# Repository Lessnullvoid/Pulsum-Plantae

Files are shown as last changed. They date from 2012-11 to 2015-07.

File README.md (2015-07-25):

# Pulsum-Plantae
Pulsum Plantae is a project focused on bioelectrical activity readings from different types of plants. Using their perceptual skills as biosensors, amplifying the signals to be sent to a microncontrolador and to work with them in a process of experimental sonification. This repository contains all the parts necessary to make pulsum plantae system run. Check our website for other examples http://lessnullvoid.cc/pulsum send us and email at info@interspecifics.cc 

The Plants, Leslie Garcia, Thiago Hersan, Paloma López and many other collaborators. 

#Hardware
The LM324N is the core of the circuit, consists of four independent, high-gain, internally frequency-compensated operational amplifiers designed specifically to operate from a single power supply over a wide range of voltages. for more information read the datashet: http://pdf.datasheetcatalog.com/datasheet/philips/LM324N.pdf
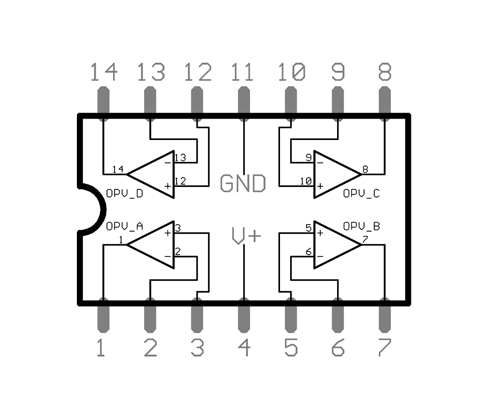
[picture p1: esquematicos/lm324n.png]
Operation Amplifier


**Biosensor circuit for bio-electrical readings**
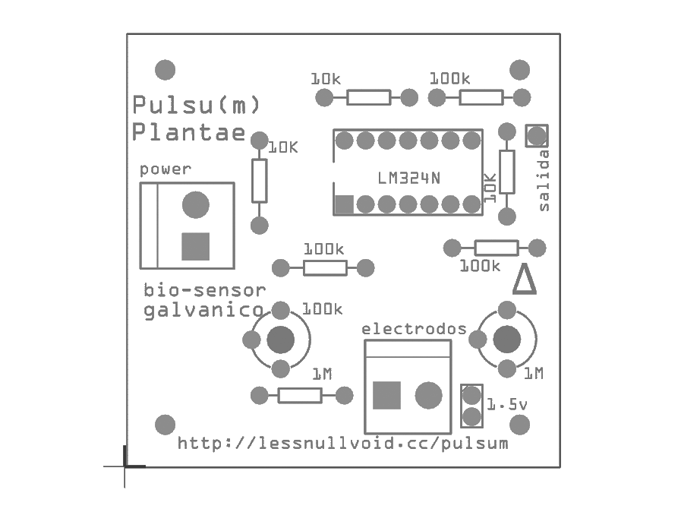
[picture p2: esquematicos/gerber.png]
Gerber file


- [Download Fritzing file here:](https://github.com/Lessnullvoid/Pulsum-Plantae/blob/master/pcb/GalvanicoLM324Final.fzz)
- [Download the pdf etchable file here:](https://github.com/Lessnullvoid/Pulsum-Plantae/tree/master/pcb/pdfLM324Final)
- [Download the gerber file here:](https://github.com/Lessnullvoid/Pulsum-Plantae/tree/master/pcb/GalvanicoLM324_Gerber_Final)
- [We have some circuits available to sell, just send us an email](info@interspecifics.cc)

**List of components for the circuit:**
- 1 LM324N
- 3 100K resistors
- 3 10K resistors
- 1 1M resistor
- 1 100K trimpot
- 1 1M trimpot
- 2 terminals
- 2 gel electrodes
- 2 acupunture needles
- 1 jumper wire

#Installation 

**Prepare your arduino and circuits**

- 1 Download the Pulsum-Plante master to your computer.
- 2 Load the pulsumSensorRead software in your arduino [find the code here.](https://github.com/Lessnullvoid/Pulsum-Plantae/blob/master/arduino/pulsumSensorRead/pulsumSensorRead.ino)
- 3 connect your circuit power terminal to the arduino power 3.3V.
- 4 plug the output pin from the pulsum circuit to your analog input in arduino.
- 5 plug your electrodes to the terminal electrodes pin in your pulsum circuit.
- 6 connect the electrodes to your plant.

#Software

- [Download a zip file with the compile version of PulsumOSC here:](http://lessnullvoid.cc/download/PulsumOscDebug.zip)
- [Compile your own PulsumOSC, fing the code here:](https://github.com/Lessnullvoid/Pulsum-Plantae/tree/master/PulsumOsc)

After preparing the circuit and pluged to the arduino board, you are ready to test the system using the software we provided here. We have a tool called PulsumOSC is a OpenFrameWorks program that runs on Mac 0SX 10.7, 10.8, 10.9, 10.10. To run the software you need to select your serial port on the serial list.

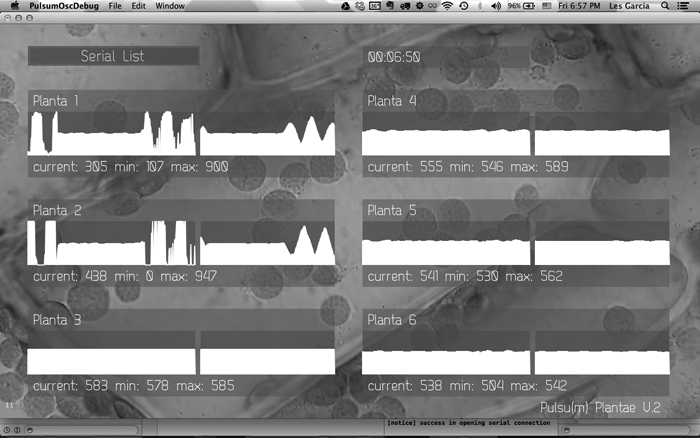
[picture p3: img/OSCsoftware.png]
PulsumOsc


After running, the software starts serving OSC values in the following arrangement: 

 ```
OSC0/filtrado/data OSC0/crudo/data OSC0/min/data OSC0/max/data
OSC1/filtrado/data OSC1/crudo/data OSC1/min/data OSC1/max/data
OSC2/filtrado/data OSC2/crudo/data OSC2/min/data OSC2/max/data
OSC3/filtrado/data OSC3/crudo/data OSC3/min/data OSC3/max/data
OSC4/filtrado/data OSC4/crudo/data OSC4/min/data OSC4/max/data
```
The number after the OSC indicates the analog input where you pluged the sensor.

This values are processed in the sensor.h file as follows:
 ```
const unsigned short getMin() const;
const unsigned short getMax() const;
const unsigned short getRawValue() const;
const unsigned short getAverageValue() const;
const unsigned short getAverageValueNormalized() const;
 ```
 **Note for linux and windows users**
 
There is also a processing version of this software to perform the same transmision of data in OSC you can check the [code here.](https://github.com/Lessnullvoid/Pulsum-Plantae/tree/master/processing/PulsumOsc)

**DSP PureData and other programs**

After running any of this software's your ar good to run the puredata part in the system. This specific patch is a granular synth. Is important to preload a sound sample on every module. By default the outputs are setup in a quadraphonic arrangement, so every module send to ~DAC1 ~DAC2 ~DAC3 and so on. You can control this on the output panel. 
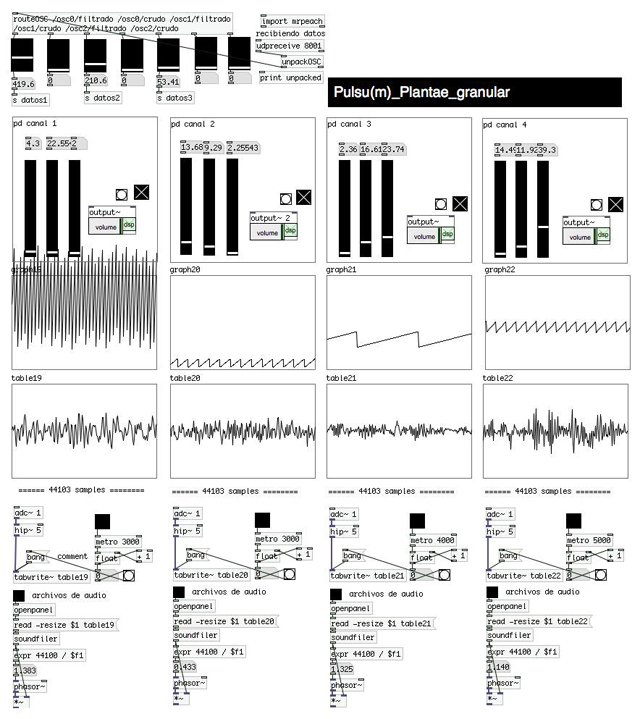
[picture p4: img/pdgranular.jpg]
pd granular
 
 
 **Start the patch**
 - Load a grain of sound 0.1 milisecond on loadpanel for every channel
 - High the volume on the output~ box 
 - Ajust the OSC data receiver on the routeOSC part to match your prefered arrangment 
 - The OSC data es controlling 3 parameters for every granular synth, frequency, amplitud, position.
 - Listen to your plants playing granular synths :)

This is a first version of the software for sonification. Both versions are available. 
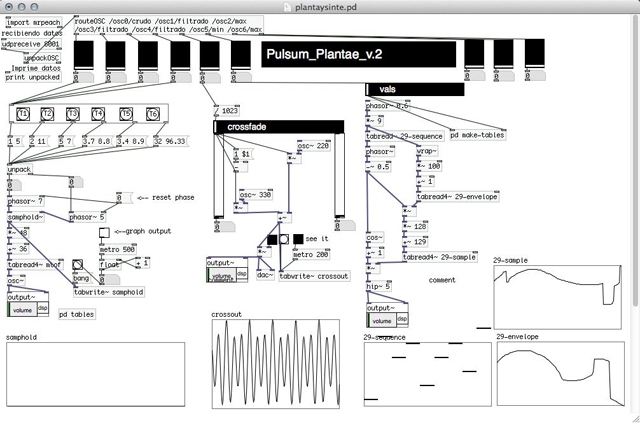
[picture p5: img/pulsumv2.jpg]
pd plantSynth
 

#Some notes on electrodes

Here is three different types of electrodes to plug your plants, this depends on the physiological features of the plant you are attempting to connect. For best results we recommend to test the three options and check the results with the monitor software.

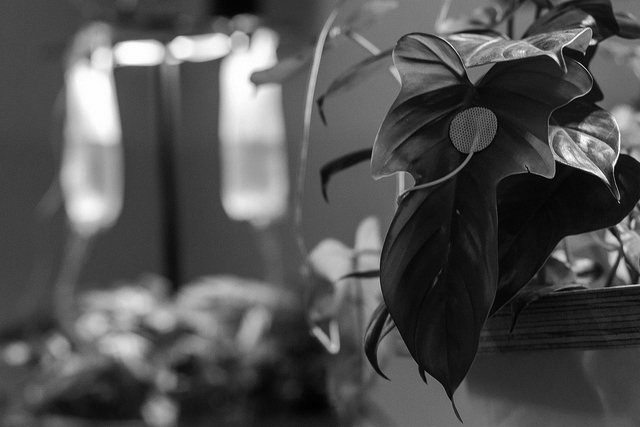
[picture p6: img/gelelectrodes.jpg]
Gel electrodes for long leaves
- The gel electrodes are specially good for long leaves, the best are the circular ones use for facial treatment. They are small and reusable, so you can clean after using, just with a little of wather: 

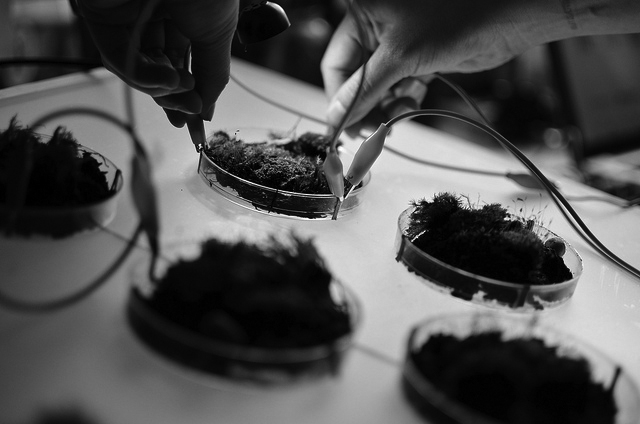
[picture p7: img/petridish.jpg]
Petridish
- The petri dish system uses aluminum tape place in a Y form. This type of electrodes work with mosses or algae or other type of small plants. You can also work with copper tape, but is important to consider the process of corrosion is faster on copper than aluminum. And this could poison your plants. 

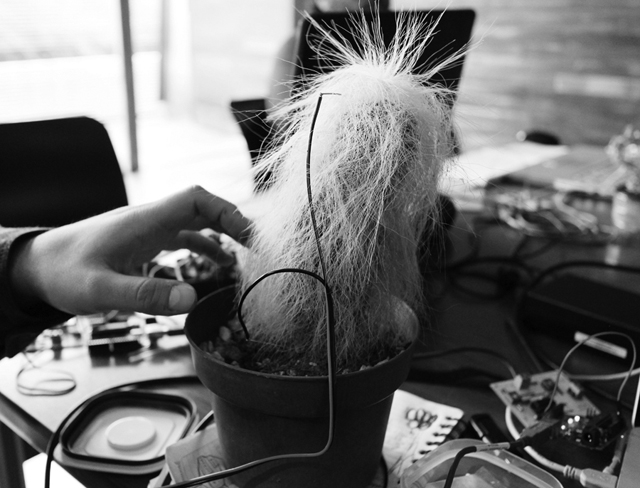
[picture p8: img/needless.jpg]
Needles
- The acupuncture  needles are specially good for cactacea or suculente type of plants, they are made out stainless steel, that means you can leave the needles inside the cactus for long time with no problems.

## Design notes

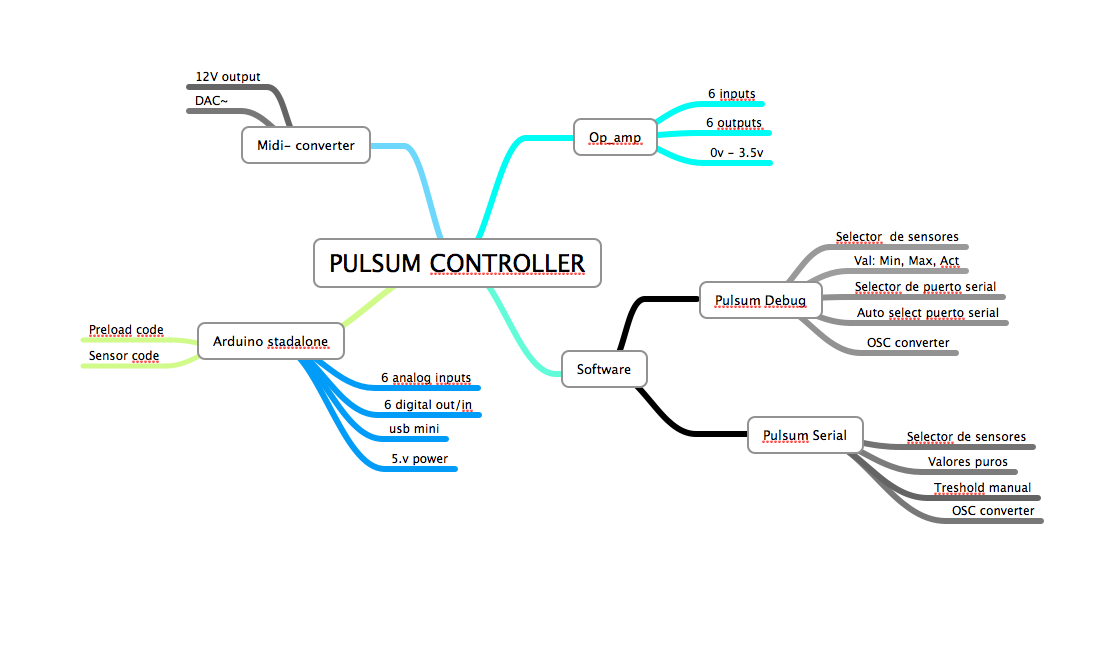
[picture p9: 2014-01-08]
diagramas/PulsumV3.png

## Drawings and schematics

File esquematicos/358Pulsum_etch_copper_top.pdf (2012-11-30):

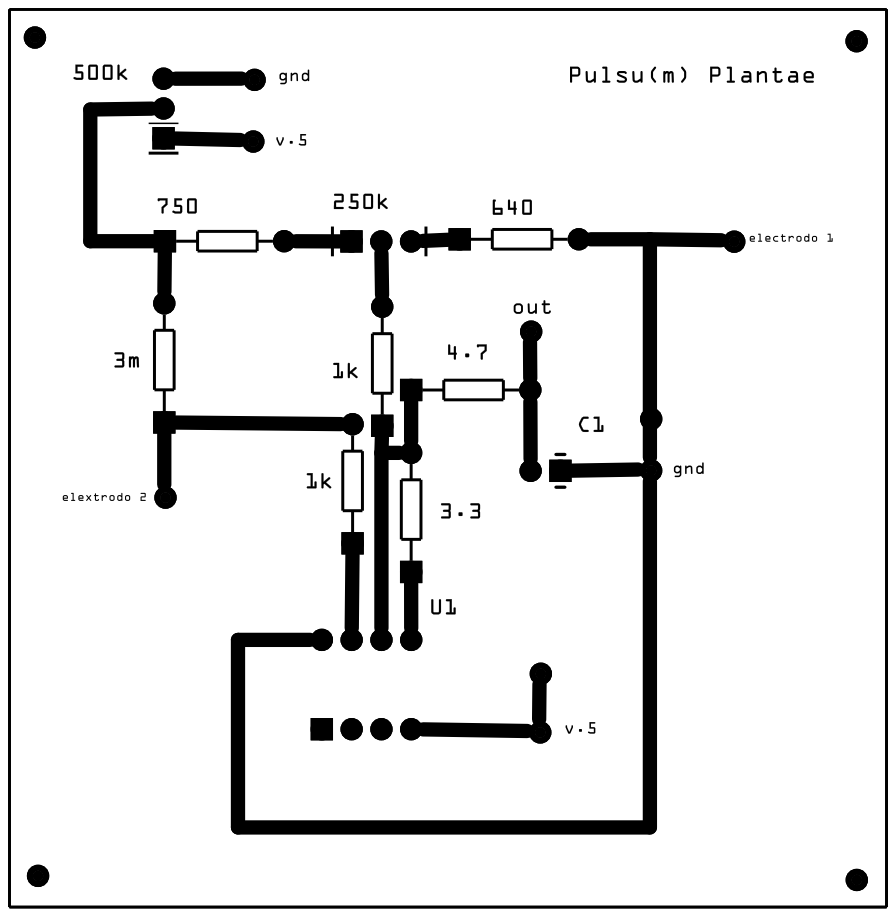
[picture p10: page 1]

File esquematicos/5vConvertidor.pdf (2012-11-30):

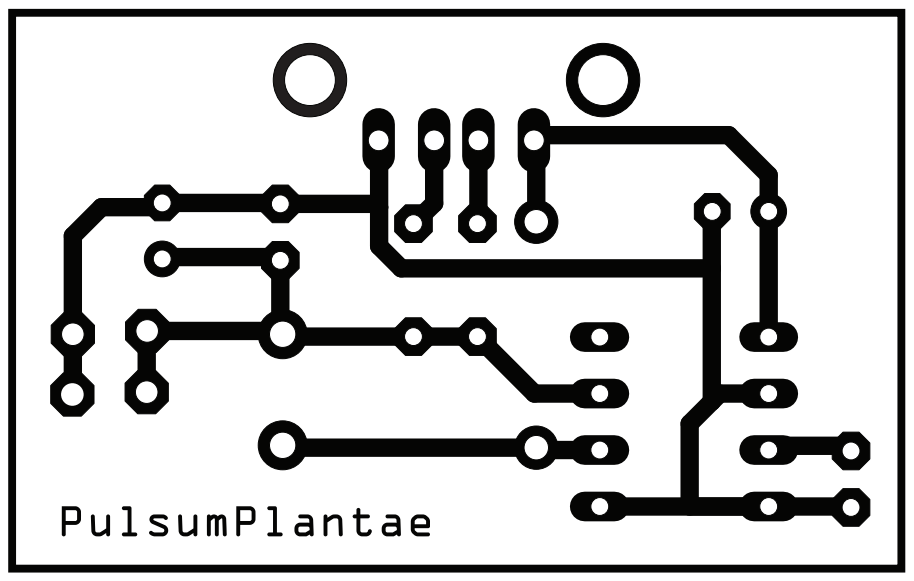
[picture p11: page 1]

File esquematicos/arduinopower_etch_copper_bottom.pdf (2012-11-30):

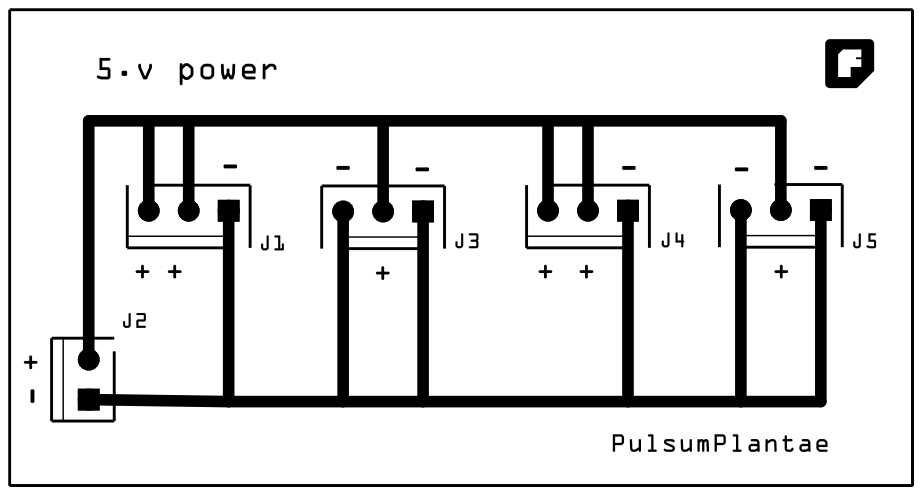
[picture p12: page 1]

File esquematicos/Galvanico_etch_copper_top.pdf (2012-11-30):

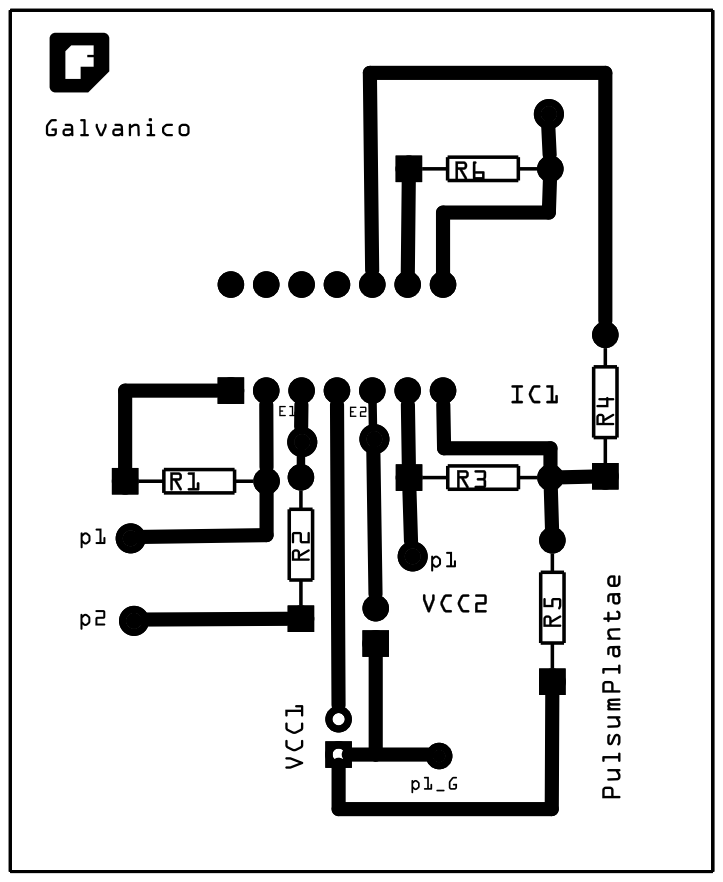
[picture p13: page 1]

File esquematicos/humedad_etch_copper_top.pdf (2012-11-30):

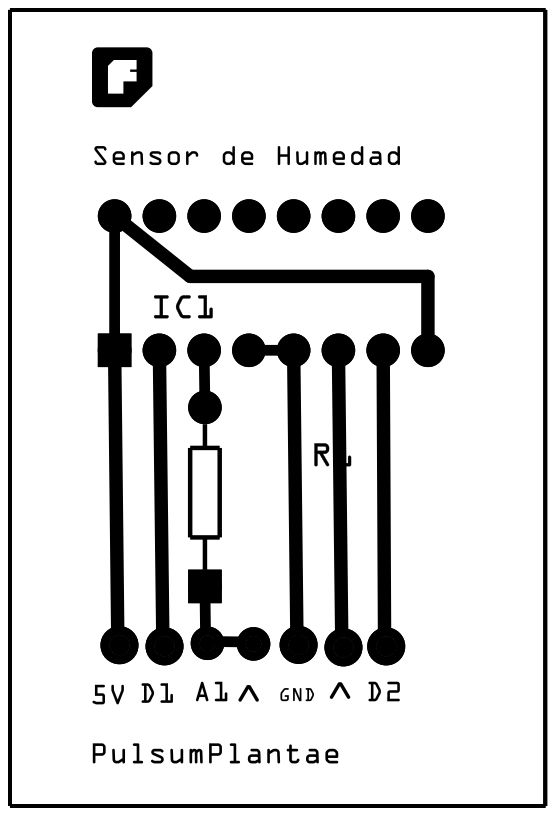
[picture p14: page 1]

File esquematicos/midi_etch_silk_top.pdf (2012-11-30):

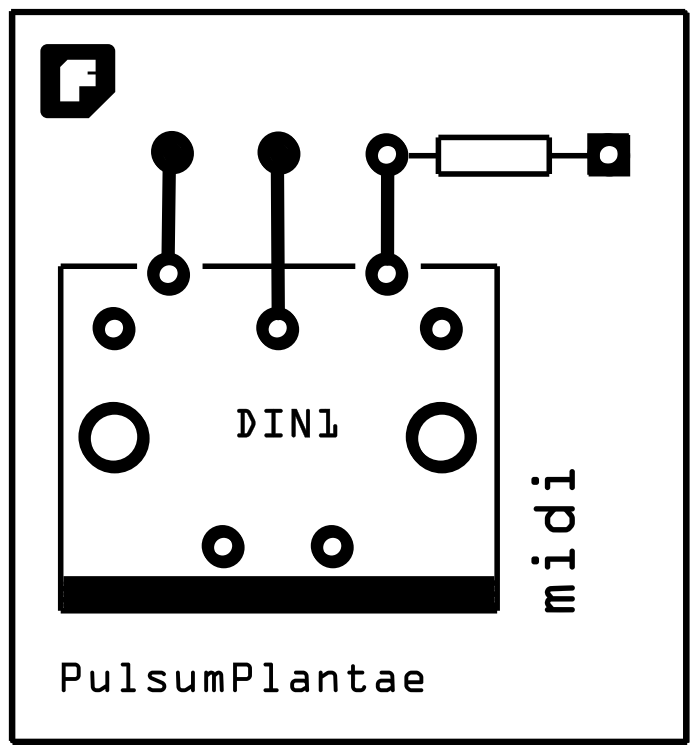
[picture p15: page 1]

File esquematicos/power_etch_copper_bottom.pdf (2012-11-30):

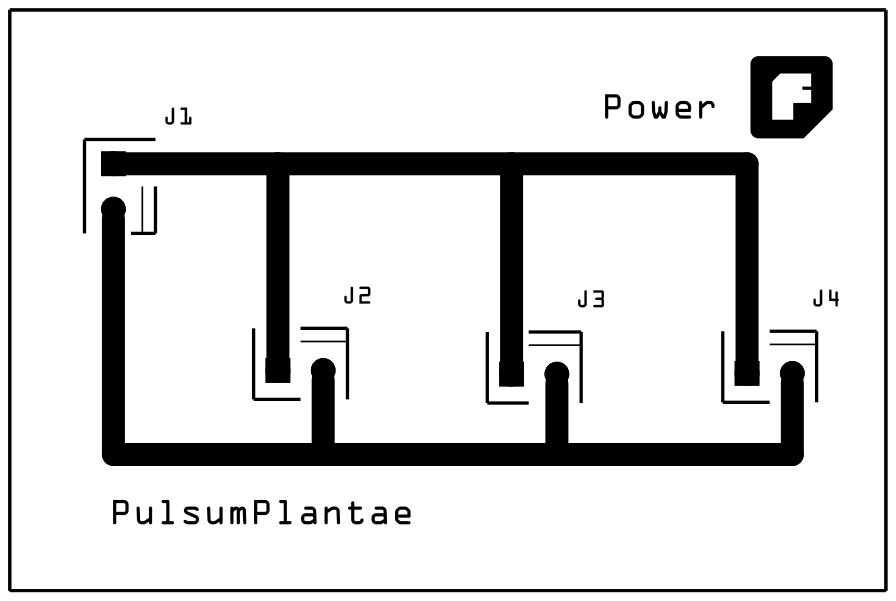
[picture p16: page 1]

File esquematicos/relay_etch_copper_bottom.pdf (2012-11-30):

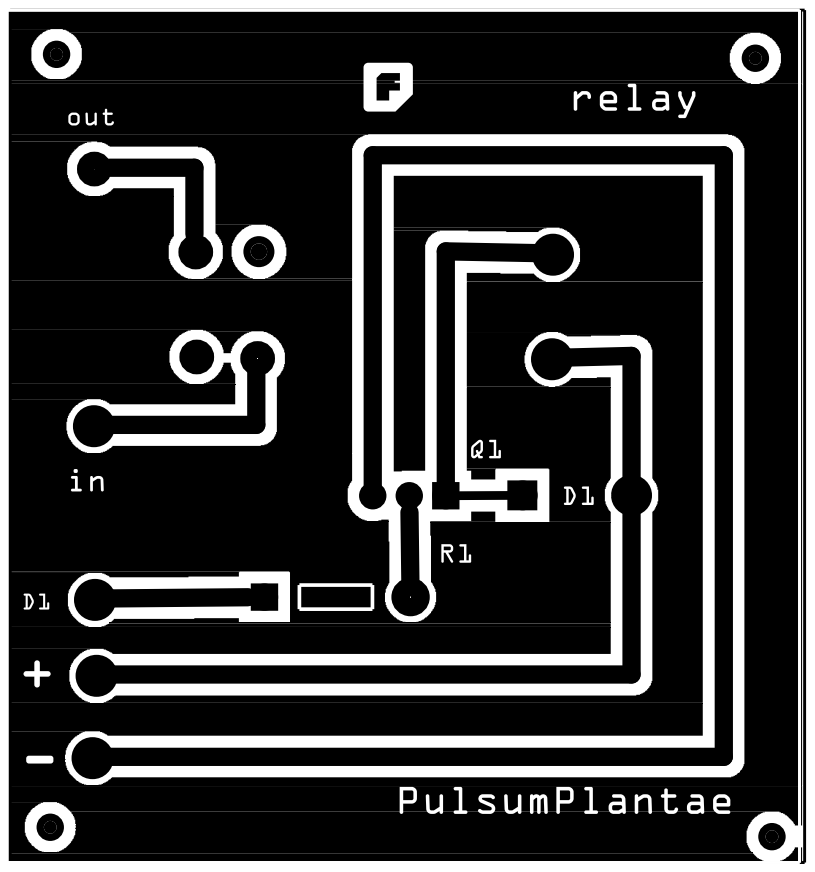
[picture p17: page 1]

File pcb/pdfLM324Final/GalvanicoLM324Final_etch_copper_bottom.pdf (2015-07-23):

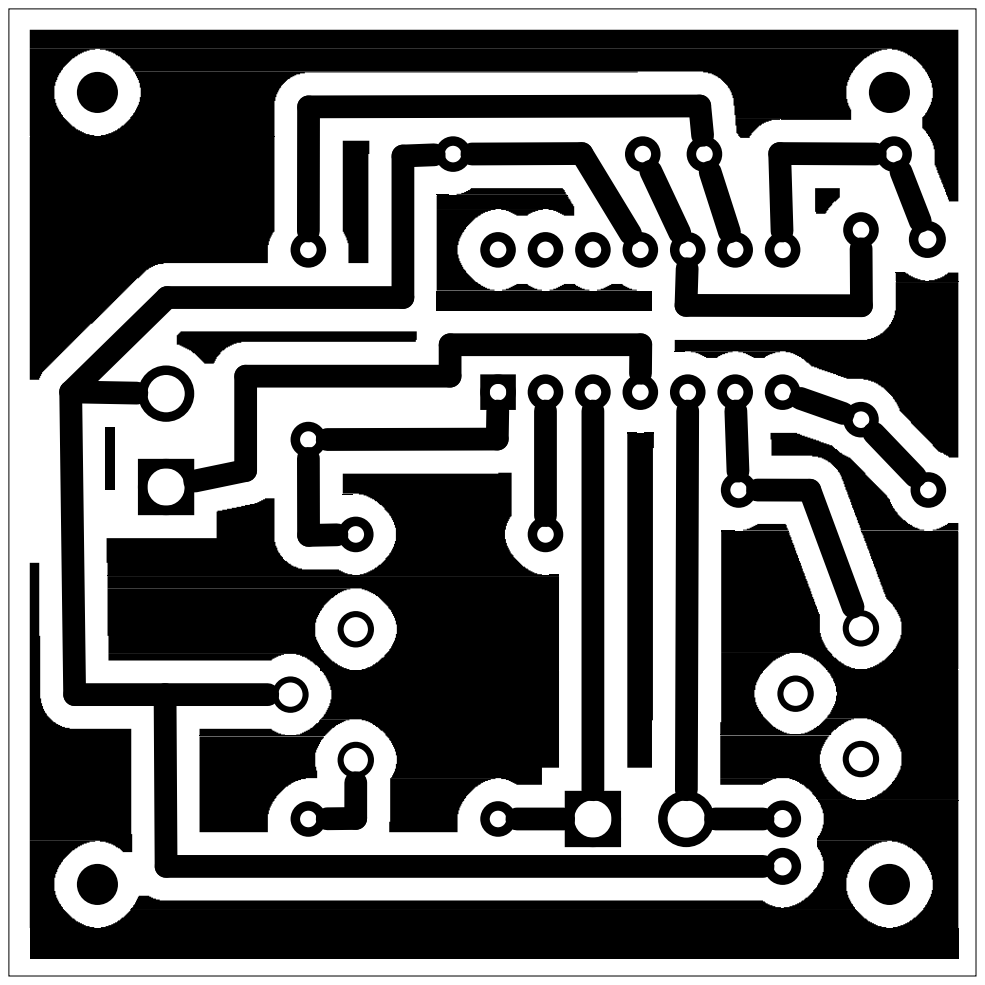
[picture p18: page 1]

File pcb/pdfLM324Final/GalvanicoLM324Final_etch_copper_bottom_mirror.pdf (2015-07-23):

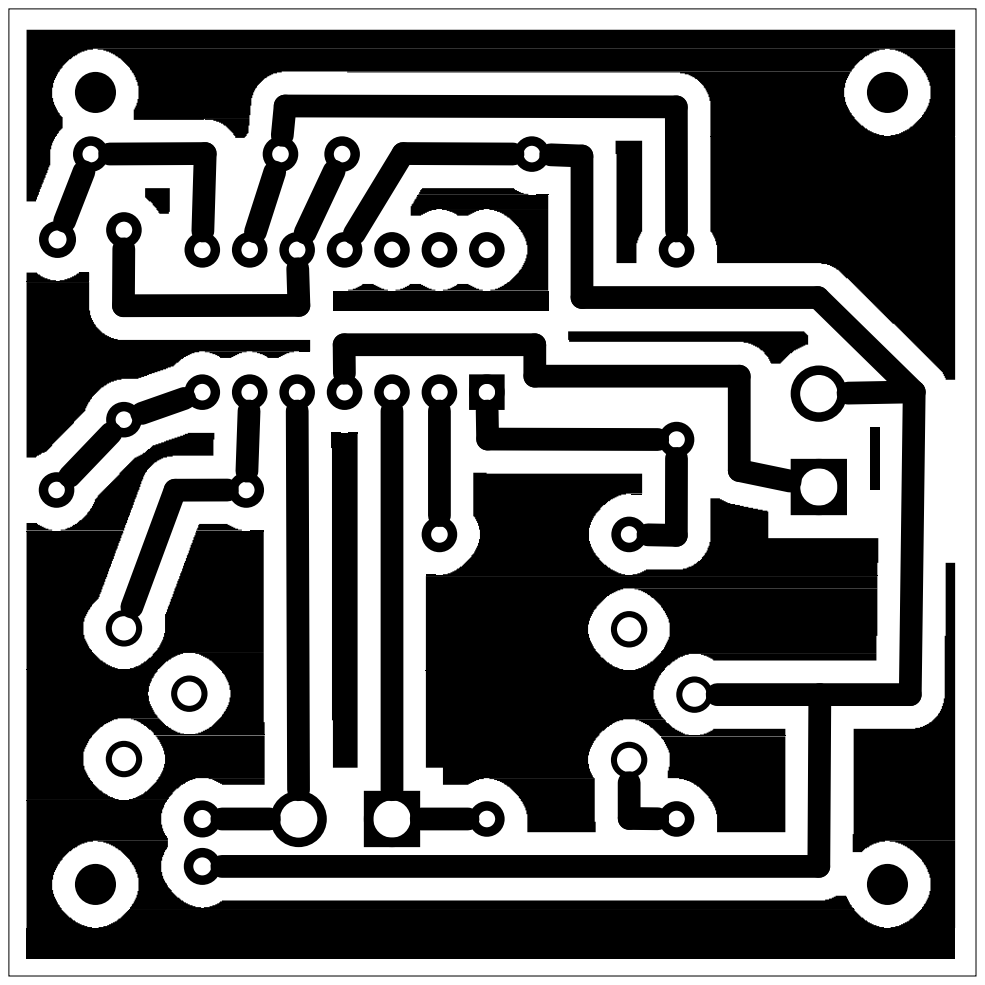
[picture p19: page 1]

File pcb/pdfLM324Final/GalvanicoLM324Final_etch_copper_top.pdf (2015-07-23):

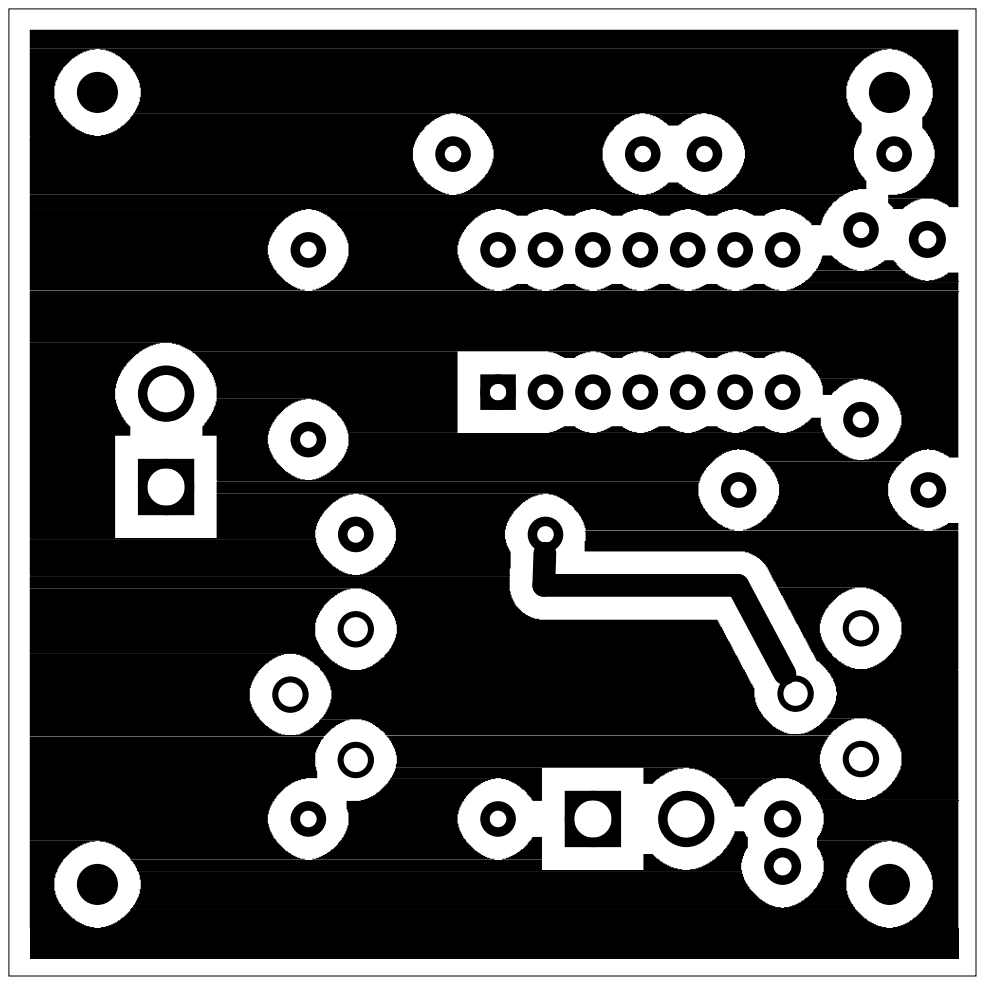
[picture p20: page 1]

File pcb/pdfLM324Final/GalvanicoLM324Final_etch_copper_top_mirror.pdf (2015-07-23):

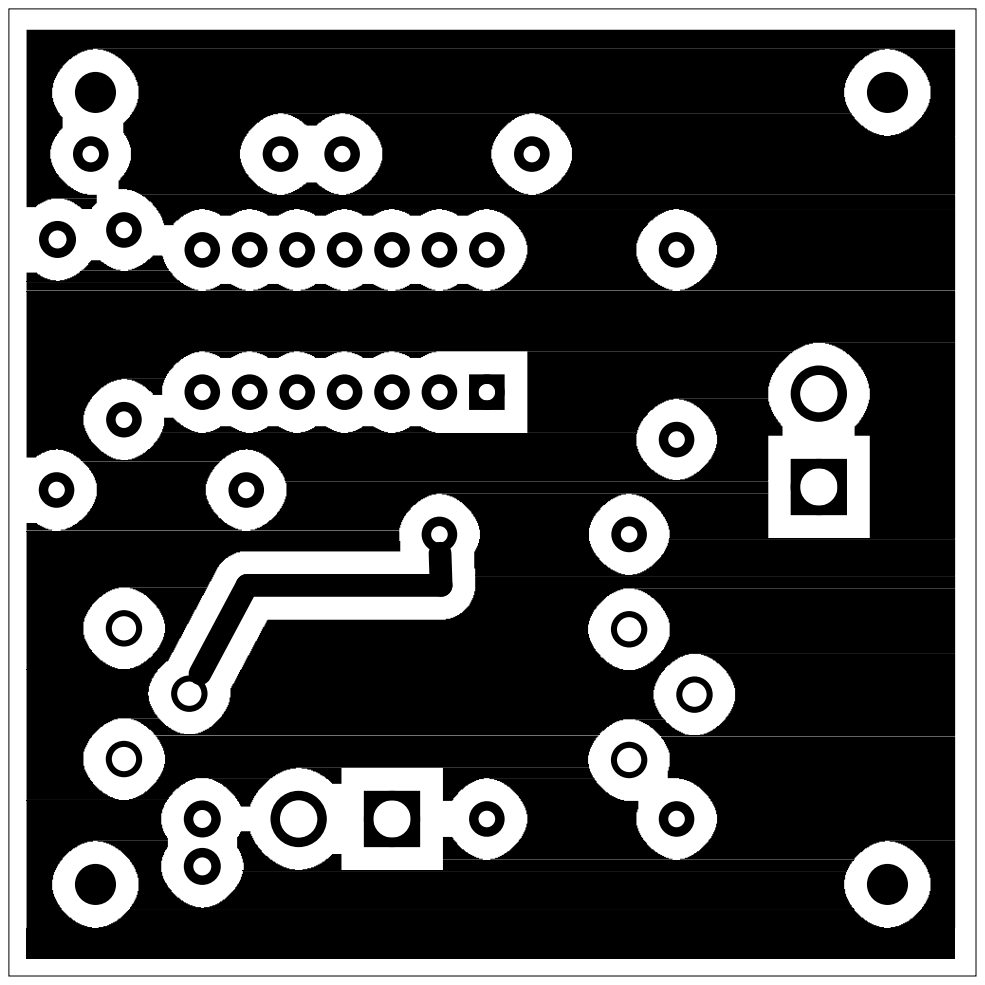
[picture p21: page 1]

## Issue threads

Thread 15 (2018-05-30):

Pulsu(m) Plantae board components

gilfuser, 2018-05-30:
Hi there.
I hope there still someone out there looking this.
I'm doing a board following your steps. First in the breadboard to see how it works and if I'm able do it anyway.
I'm unsure about the components.
I would like to ask you if there is a picture of the board where I could identify the components. Specially the 1.5 pins, power and salida.

Thank in advance.

bests,
Gil

b01xy, 2018-06-12:
maybe here : https://i2.wp.com/farm9.staticflickr.com/8524/8670196247_da17ccacaa_k_d.jpg?resize=1000%2C562&ssl=1 + webpage http://interspecifics.cc/work/pulsum-plantae-2012/

unicornrobot, 2019-10-27:
I found this to help me with board components - https://slideplayer.org/slide/6133925/

antoinejaunard, 2020-05-26:
Hi @gilfuser @b01xy @unicornrobot,

Have you found a component list, or a easier way to prototype this board?

Thank you,
Antoine

Hf316, 2021-04-20:
hi @antoinestudio
did you ever figure this out? Thanks

antoinestudio, 2021-04-21:
Hello @Hf316,

Unfortunately not entirely. But in the meantime, I made a prototype/project using more or less the same approach. I documented it on my website > [https://antoine.studio/green-observatory.html](https://antoine.studio/green-observatory.html)

gilfuser, 2021-07-05:
Beautiful stuff, @antoine3000

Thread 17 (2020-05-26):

Ways to measure the electrical activity of plants

antoinejaunard, 2020-05-26:
Hi @Lessnullvoid,

I'm trying to measure the electrical activity of plants, and I found two differents approach of doing so.

the first one is yours, using operational amplifiers.

The other one is from Data Garden, which is done by using a 555 timer IC to "graph changes in galvanic response by producing a square wave of variable frequency and pulse width" ([source 1](http://philadelphia.thedelimagazine.com/9336/fyi-on-diys-phl-data-garden), [source 2](https://www.npr.org/2020/02/21/807821340/the-lessons-to-be-learned-from-forcing-plants-to-play-music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))

Could you explain (at least briefly) what are the main differences in these two ways of sensing? Are they collecting the same type of data?

Muchas gracias,
Antoine

nearlynight, 2020-05-26:
Hi @antoinejaunard

I wrote my thesis about the topic of human-plant interaction and also did research on the different approachs on how to gather signals from plants.
Most written material can be found under "news and publication" here: https://sonnengartenjena.wordpress.com/

One chapter of my thesis covers the different approaches (chapter 3). While the thesis is in German almost all sources should be in English.
If you've any further questions please get in touch with me - I'd be happy if I could help out :)

Best
Till

antoinejaunard, 2020-05-27:
Hi @nearlynight,
I will read/translate your third chapter, thank you very much!
Have a nice day,
Antoine

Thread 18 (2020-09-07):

What does the circuit actually do?

kiyu-git, 2020-09-07:
Hi there,
thank you for great jobs.
I want to know what the circuit actually do.
I found this circuit is a kind of instrumentation amp with 1.5V dc offset, but I can't find a some implementations of it.
1) What is  a function of 100k trimpot which is connected with 1M resistor and ground?
2) Why is a resistor which is connected PIN8 and PIN 9 of LM324N 100K not but 10K (I guess it should be the same resistance as a resistor which is connected with PIN10 and ground, if the circuit is a kind of instrumentation amp).

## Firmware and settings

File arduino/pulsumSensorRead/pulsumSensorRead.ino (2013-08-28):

// number of analog pins to read
#define NUMPINS 6

// read at most 100 times a second
#define READPERIOD 5

// a header for outgoing serial messages
#define MSGHEADER 0xAB

byte serialMsg[3];
int whichPin;
unsigned long lastReadWrite;

void setup() {
  Serial.begin(57600);
  serialMsg[0] = serialMsg[1] = serialMsg[2] = 0x00;
  whichPin = 0;
  lastReadWrite = millis();
}

void loop() {
  // don't read pins more frequent than 100 times per second
  // and only read one pin per loop to avoid noise
  if(millis()-lastReadWrite > READPERIOD){
    short readValue = analogRead(whichPin);

    // send 3 bytes per value: HHHH_HHHH AAAA_VVVV VVVV_VVVV
    // where HHHH_HHHH = 8-bit fixed header
    //       AAAA = which pin [0,15]
    //       VVVV VVVV_VVVV = 12 bits of data [0,4095]

    serialMsg[0] = (MSGHEADER&0xFF);
    serialMsg[1] = ((whichPin<<4)&0xF0) | ((readValue>>8)&0x0F);
    serialMsg[2] = (readValue&0xFF);

    Serial.write(serialMsg[0]);
    Serial.write(serialMsg[1]);
    Serial.write(serialMsg[2]);

    Serial.flush();
    whichPin = (whichPin+1)%NUMPINS;
    // use millis() because flush could take longer
    lastReadWrite = millis();
  }
}

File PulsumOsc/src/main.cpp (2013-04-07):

#include "ofMain.h"
#include "PulsumOsc.h"
#include "ofAppGlutWindow.h"

//========================================================================
int main( ){

    ofAppGlutWindow window;
	ofSetupOpenGL(&window, 1280,720, OF_WINDOW);			// <-------- setup the GL context

	// this kicks off the running of my app
	// can be OF_WINDOW or OF_FULLSCREEN
	// pass in width and height too:
	ofRunApp( new PulsumOsc());

}

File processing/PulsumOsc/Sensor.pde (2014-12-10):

import oscP5.*;
import netP5.*;

private static NetAddress oscOutAddress;
private static OscMessage mMessage;

public class Sensor {
  private static final short AVGSIZE = 20;
  private static final short DISPLAYSIZE = 300;
  private static final short RAWSIZE = 30000;

  private final static int OSC_OUT_PERIOD = 100;
  private final static int OSC_OUT_PORT = 8666;
  private final static String OSC_OUT_HOST = "localhost";
  private final static String OSC_OUT_PATTERN = "/pulsum-osc/";

  private short rawValues[] = new short[RAWSIZE+1];
  private short averageValues[] = new short[DISPLAYSIZE*2+1];
  private short currentRunningAverage[] = new short[AVGSIZE];
  private int averageSum;
  private short averageIndex;

  // begin/end indices for different things
  private short averageEnd, rawEnd;
  private short maxValue, minValue;
  private String name;
  private PVector location, dimension;

  public Sensor(PVector _location, PVector _dimension, String _name) {
    oscOutAddress = new NetAddress(OSC_OUT_HOST, OSC_OUT_PORT);
    mMessage = new OscMessage(OSC_OUT_PATTERN);

    // set location/dimension of graphs and name of sensor
    location = _location;
    dimension = _dimension;
    name = _name;

    // initial end indices
    //   "end" points to one after the last value in range
    rawEnd = (short)((rawValues.length)-1);
    averageEnd = (short)((averageValues.length)-1);

    // init values
    for (int i=0; i<(rawValues.length); ++i) {
      rawValues[i] = 0;
    }
    for (int i=0; i<(averageValues.length); ++i) {
      averageValues[i] = 0;
    }
    for (int i=0; i<(currentRunningAverage.length); ++i) {
      currentRunningAverage[i] = 0;
    }

    minValue = (short)0x7fff;
    maxValue = 0;
    averageSum = 0;
    averageIndex = 0;
  }


  public short getMin() {
    return minValue;
  }
  public short getMax() {
    return maxValue;
  }
  public String getName() {
    return name;
  }

  public short getRawValue() {
    // last written value is at end-1
    // make sure index is positive
    int getFromIndex = (rawEnd > 0)?(rawEnd-1):((rawValues.length)-1);
    return rawValues[getFromIndex];
  }

  public short getAverageValue() {
    // last written value is at end-1
    // make sure index is positive
    int getFromIndex = (averageEnd > 0)?(averageEnd-1):((averageValues.length)-1);
    return averageValues[getFromIndex];
  }
  public short getAverageValueNormalized() {
    return (short)constrain((short)map(getAverageValue(), getMin(), getMax(), 0, 1023), 0, 1023);
  }


  public void addValue(short val) {
    // write value to raw array and update end index
    rawValues[rawEnd] = val;
    rawEnd = (short)((rawEnd+1)%(rawValues.length));

    // update running average
    averageSum -= currentRunningAverage[averageIndex];
    currentRunningAverage[averageIndex] = val;
    averageSum += currentRunningAverage[averageIndex];
    averageIndex = (short)((averageIndex+1)%(currentRunningAverage.length));

    // write to average values
    averageValues[averageEnd] = (short)(averageSum/(currentRunningAverage.length));
    averageEnd = (short)((averageEnd+1)%(averageValues.length));

    // find min/max of current averages
    short thisMinValue = (short)0x7fff;
    short thisMaxValue = 0;
    for (int i=0; i<(averageValues.length); ++i) {
      if (averageValues[i] > thisMaxValue) {
        thisMaxValue = averageValues[i];
      }
      if (averageValues[i] < thisMinValue) {
        thisMinValue = averageValues[i];
      }
    }

    // if there's a new min/max, update immediately
    //    else, slowly approach current min/max
    if (thisMaxValue > maxValue) {
      maxValue = thisMaxValue;
    }
    else {
      maxValue = (short)(0.99*maxValue + 0.01*thisMaxValue);
    }

    if (thisMinValue < minValue) {
      minValue = thisMinValue;
    }
    else {
      minValue += (short)(0.01*thisMinValue);
      minValue = (thisMinValue<minValue)?thisMinValue:minValue;
    }
  }

  public void sendOsc() {
    String mAddrPatt = OSC_OUT_PATTERN+getName()+"/";

    // min
    mMessage.clear();
    mMessage.setAddrPattern(mAddrPatt+"min");
    mMessage.add(getMin());
    OscP5.flush(mMessage, oscOutAddress);

    // max
    mMessage.clear();
    mMessage.setAddrPattern(mAddrPatt+"max");
    mMessage.add(getMax());
    OscP5.flush(mMessage, oscOutAddress);

    // filtered
    mMessage.clear();
    mMessage.setAddrPattern(mAddrPatt+"filtrado");
    mMessage.add(getAverageValueNormalized());
    OscP5.flush(mMessage, oscOutAddress);

    // raw
    mMessage.clear();
    mMessage.setAddrPattern(mAddrPatt+"crudo");
    mMessage.add(getRawValue());
    OscP5.flush(mMessage, oscOutAddress);
  }

  public void draw() {
    pushMatrix();
    translate(location.x, location.y);

    // background rectangle
    fill(100);
    rect(0, 0, dimension.x*11/12, dimension.y);

    // sensor title
    fill(255);
    textSize(16);
    text(name, 10, 16);

    // raw graph
    pushMatrix();
    translate(0, dimension.y/4);
    drawGraph(rawValues, (short)(rawValues.length), rawEnd, dimension.x/2, dimension.y/2);
    popMatrix();

    // avg graph
    pushMatrix();
    translate(dimension.x/2+10, dimension.y/4);
    drawGraph(averageValues, (short)(averageValues.length), averageEnd, dimension.x*5/12-10, dimension.y/2);
    popMatrix();

    // info string
    pushMatrix();
    translate(0, dimension.y*3/4);
    fill(255);
    textSize(16);
    String ss = "current: "+getRawValue()+" min: "+minValue+" max: "+maxValue;
    text(ss, 0, 16);
    popMatrix();

    popMatrix();  // translate
  }

  void drawGraph(short values[], short sizeOfValues, short lastIndex, float gwidth, float gheight) {
    // graph
    PShape ps = createShape();
    ps.beginShape();
    ps.fill(255);
    ps.vertex(0, gheight);
    for (int x=1, i=(int)(lastIndex-gwidth); x<gwidth; ++x, ++i) {
      int yIndex = i;
      while (yIndex<0) {
        yIndex += sizeOfValues;
      }
      yIndex = yIndex%sizeOfValues;

      short y0 = (short)map(values[yIndex], 1023, 0, 0, gheight);
      ps.vertex(x, y0);
    }
    ps.vertex(gwidth, gheight);
    ps.endShape(CLOSE);

    // background rectangle
    fill(90);
    noStroke();
    rect(0, 0, gwidth, gheight);
    shape(ps, 0, 0);
  }
}

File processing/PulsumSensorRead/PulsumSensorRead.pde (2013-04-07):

import processing.serial.*;

Serial port;
int val;
int[][] values;
PVector graphDim;

color[] someColors = {
  #137f5e, #628c73, #92c099, #358e44, #6d9a50, #4d6045
};

void setup() {
  size(1280, 720);
  frameRate(60);
  println(Serial.list());
  port = new Serial(this, Serial.list()[4], 57600);
  graphDim = new PVector(width/2, height/3);
  values = new int[6][(int)graphDim.x];
  smooth();
}

void draw() {
  background(20, 30, 20);

  for (int j=0; j<2; j++) {
    pushMatrix();
    translate(j*graphDim.x, 0);
    for (int i=0; i<3; i++) {
      pushMatrix();
      translate(0, i*graphDim.y);
      stroke(someColors[j*3+i]);
      fill(someColors[j*3+i]);
      drawGraphShape(values[j*3+i]);
      popMatrix();
    }
    popMatrix();
  }
}

void serialEvent(Serial p) { 
  while (p.available () > 2) {
    if (p.read() == 0xAB) {
      int u = p.read();
      int l = p.read();

      for (int i=0; i<(int)graphDim.x-1; i++) {
        values[(u>>4)&0x07][i] = values[(u>>4)&0x07][i+1];
      }
      values[(u>>4)&0x07][(int)graphDim.x-1] = ((u<<8)&0x0F00) | (l&0xFF);
    }
  }
} 

int getY(int val) {
  return (int)(graphDim.y - (val / 1023.0f * graphDim.y));
}

void drawGraphLine(int[] vs) {
  strokeWeight(2);
  for (int x=1; x<graphDim.x; x++) {
    line(x-1, getY(vs[x-1]), x, getY(vs[x]));
  }
}

void drawGraphShape(int[] vs) {
  strokeWeight(2);
  beginShape();
  vertex(0, getY(0));
  for (int x=0; x<graphDim.x; x++) {
    vertex(x, getY(vs[x]));
  }
  vertex(graphDim.x, getY(0));
  endShape(CLOSE);
}

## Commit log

2012-04-10 Lector de sensores analogos
    para arduino
2012-10-22 OSC ARDUINO
2012-11-30 Archivos de los pcb's en formato pdf
2013-01-12 gerber files pulsum
    [Galvanico358.fzz, GalvanicoLM324n.fzz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]
2013-04-04 Actualización con etiquetas
    [Galvanico358.fzz, GalvanicoLM324n.fzz]
2013-04-05 diseñando visualización de lecturas maximas y minimas
2013-04-06 create arduino directory for sensorcheck sketch
2013-04-07 add new arduino code for sensors
2013-04-07 add processing code to test/visualize the new arduino code
2013-04-07 add Sensor class to keep track of and draw sensor data
2013-04-07 mapa de procesos
2013-04-08 programa para generar sonido via osc
2013-04-08 parametrize sensor drawing functions
2013-04-08 draw 2 graphs per sensor
2013-04-08 add time counter inside Sensor class
2013-04-08 update min/max algorithm to slowly approach the current min/max when they're not in the current samples
2013-04-08 const correct Sensor class
2013-04-08 add getters to Sensor value, min and max
2013-04-08 remove ghost of arduino2osc files
2013-04-09 add sensor name to constructor
2013-04-10 send raw values out of arduino
2013-04-10 add code to print out running time... but keep it commented out for now
2013-04-10 arduino update
2013-04-11 send average value normalized to current min and max values
2013-04-12 add some frameworks to xcode project to make videoPlayer work with sdk 10.8
2013-04-12 increase font size. add timer. add title
2013-04-13 add name getter to Sensor class
2013-04-18 add id to sensor xml tag
2013-08-28 Actualización pcb
    [GalvanicoLM324n.fzz, GalvanicoLM324nSch.fzz]
2013-08-28 actualización de patches en pd
2013-09-23 pdf pcb
2013-10-15 salidas independientes para cuadrafonia
2013-10-15 update de electrodos al pcb
    [Galvanico358.fzz]
2013-10-23 Actualizacion de archivos
2014-01-08 actualización de diseño
    [Galvanico358.fzz, GalvanicoLM324n.fzz]
2014-03-04 update smaller board
    [GalvanicoLM324n2.fzz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]
2014-12-10 adds name getter to Sensor class
2014-12-10 refactors osc-out code to the sensor object in processing/PulsumOsc
2014-12-10 makes static members private in processing/PulsumOsc/Sensor class
2015-07-23 clean up
    [Galvanico358.fzz, GalvanicoLM324Final.fzz, GalvanicoLM324n.fzz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]
2015-07-23 add gerber
2015-07-24 circuit parts
